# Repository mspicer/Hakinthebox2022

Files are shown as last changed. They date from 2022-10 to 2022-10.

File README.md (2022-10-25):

# Hack-in-the-box 2022 Badge Guide

- PCB.md contains the schematics and pcb layout for each board. This may be helpful for assembly or programming.
- PROGRAM.md contains information on flashing the boards with the current or custom code if desired.

## Assembly

### Step 1
- Solder the attiny85 to the base pcb.

Step 1
### Step 2
- Solder the first two leds on the base pcb.

Step 2
### Step 3
- Solder the last two leds on the base pcb.

Step 3
### Step 4
- Solder the first two leds on the top of the upper pcb.

Step 4
### Step 5
- Solder the next two leds on the top of the upper pcb.

Step 5
### Step 6
- Solder the first two leds on the bottom of the upper pcb.

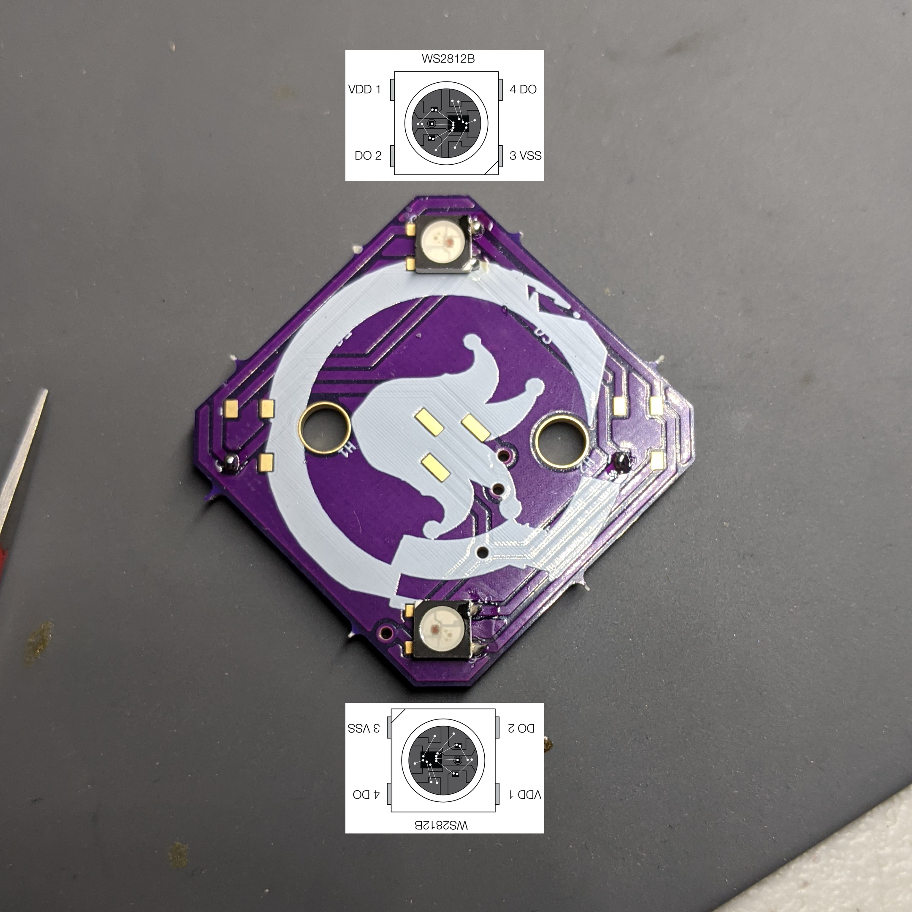
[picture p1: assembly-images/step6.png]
Step 6

### Step 7
- Solder the last two leds on the upper pcb.

Step 7
### Step 8
- Solder the headers on the board by first placing them in the expansion board or similar and then slide the board on to ensure good fit.
Step 8
### Step 9
Step 9
### Step 10
- Remove the stripped ends of the three solid-core wires and attach them to the base pcb.

Step 10
### Step 11
- Solder the solid-core wires to the top. The easiest way is to solder the outer two wires, bend them all 90 degrees, then solder the middle one.

Step 11
### Step 12
- Attach the stand offs to the base pcb with the socket cap screws.

Step 13
### Step 13
Step 14
### Step 14
- With the other screws attach the acrylic and the upper pcb to the standoffs.

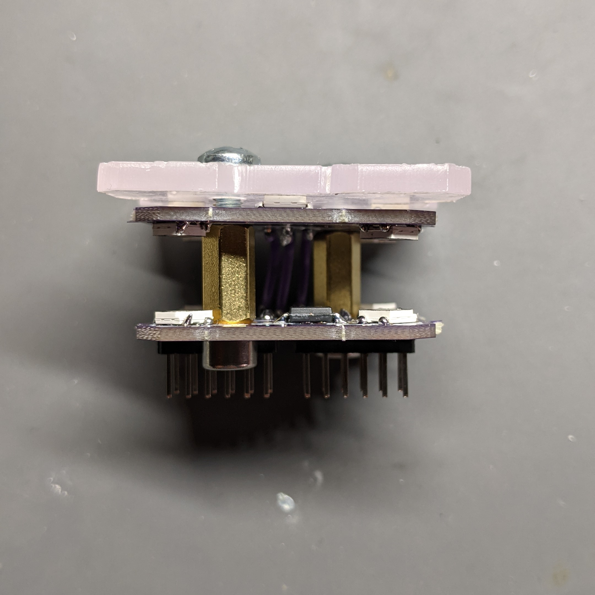
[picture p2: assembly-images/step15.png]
Step 15

### Step 15
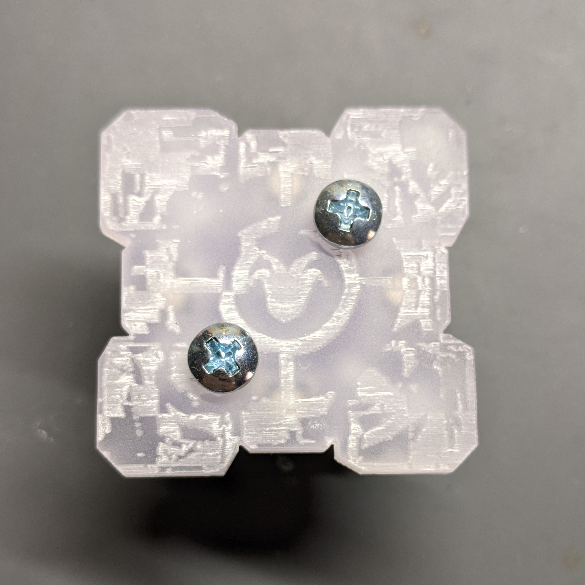
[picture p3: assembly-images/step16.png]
Step 16


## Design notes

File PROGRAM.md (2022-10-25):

# Hack-in-the-box 2022 Programming Guide
- This has been test with Arduino IDE 1.8.18

## Installing Libraries
- Install the ATtiny code by adding this url to the Additional Board Manager URLS: http://drazzy.com/package_drazzy.com_index.json
- More info on this library at https://github.com/SpenceKonde/ATTinyCore

## Programming Connections
- When looking down at the board from above only the lower right six pins are used for programming.

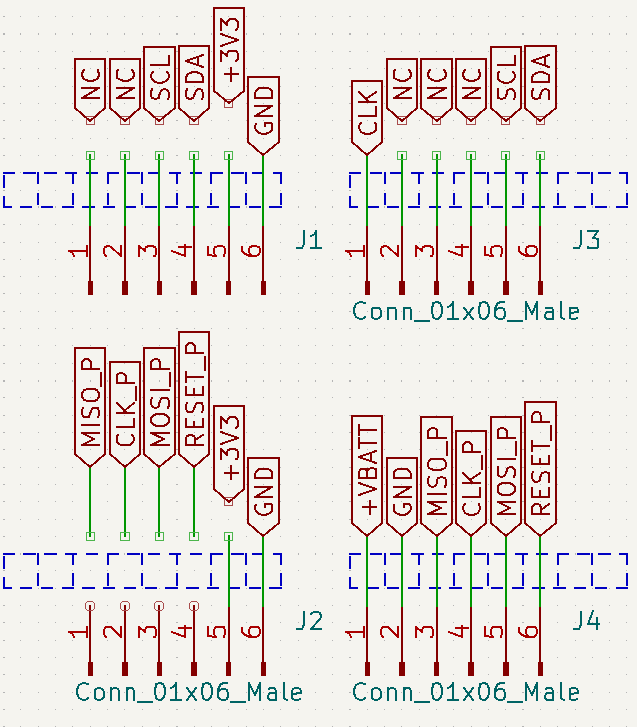
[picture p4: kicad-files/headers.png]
Headers


## Flashing Configuration
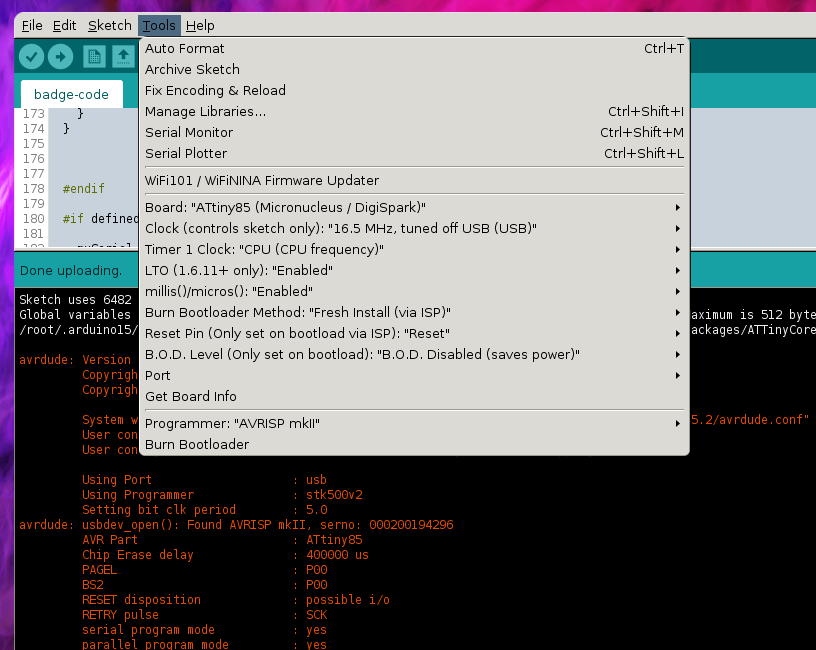
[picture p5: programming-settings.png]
Programming Config


## Flashing
- First select the programmer that you have attached and burn the bootloader
- Then double check the configuration and press Ctrl+Shift+U

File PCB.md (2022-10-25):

# Hack-in-the-box 2022 Badge Schematics and PCB Layout

## Base PCB Schematic
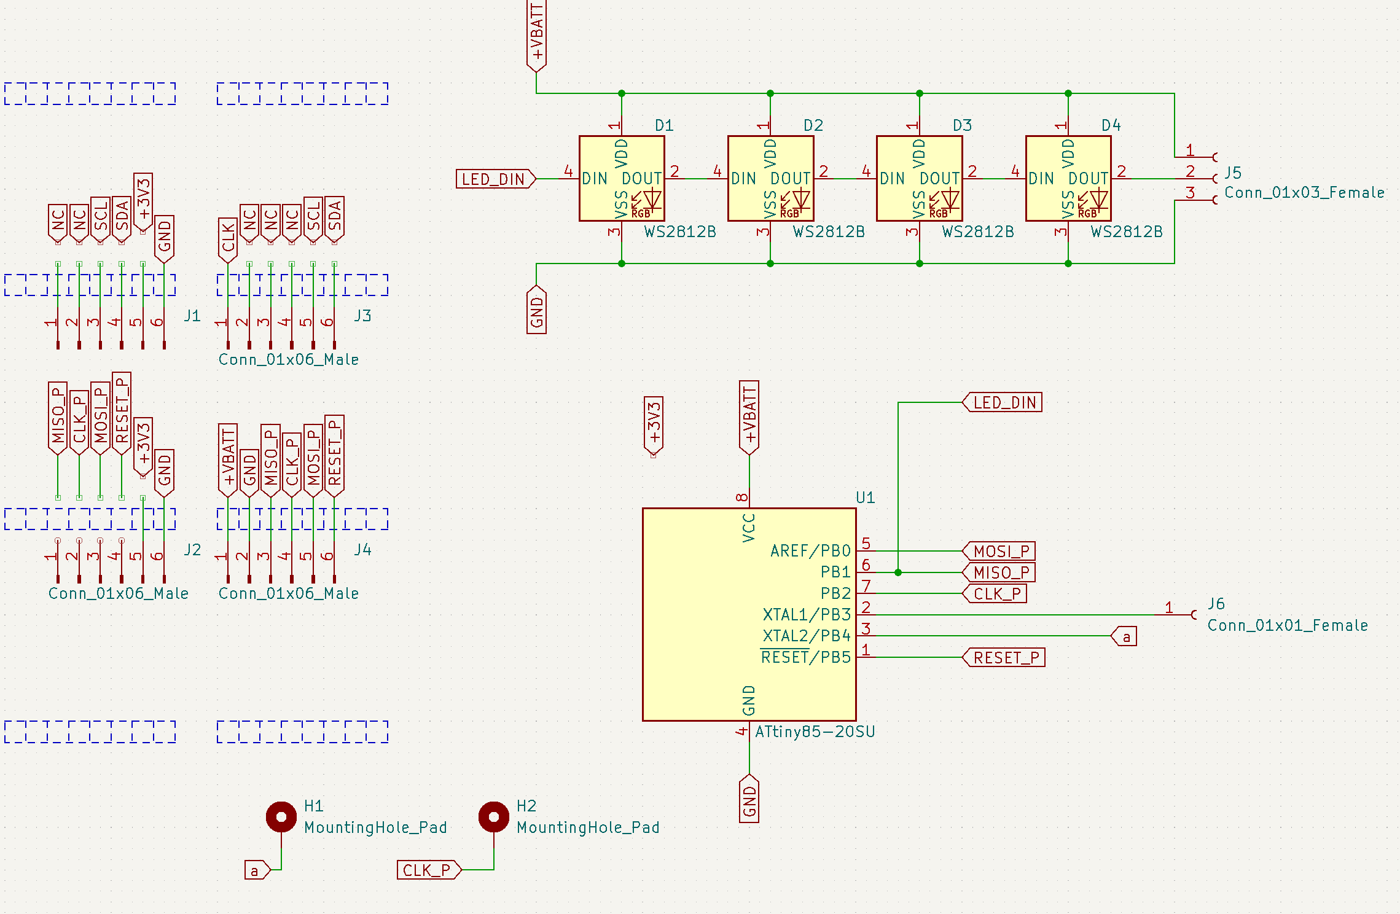
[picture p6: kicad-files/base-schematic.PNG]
Base PCB Schematic


## Upper PCB Schematic
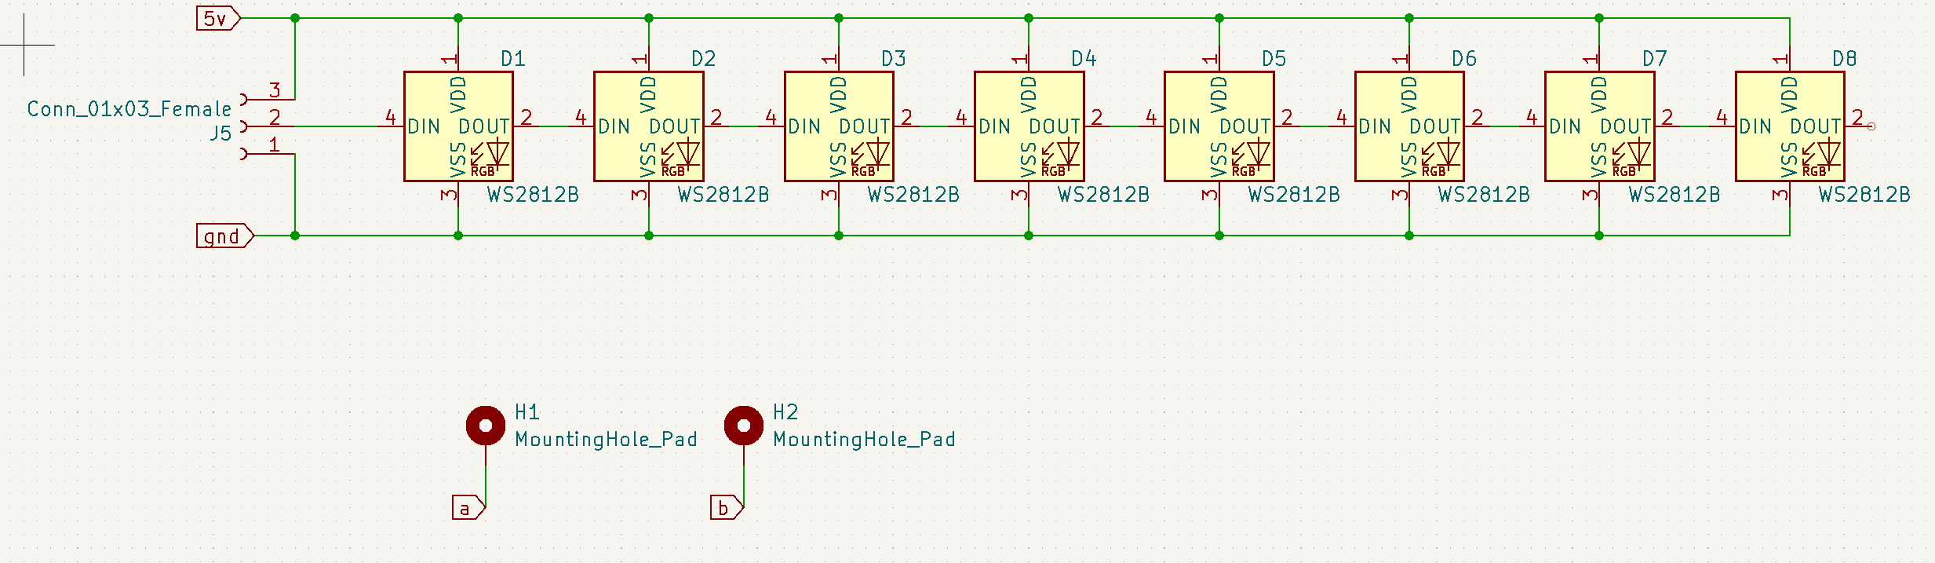
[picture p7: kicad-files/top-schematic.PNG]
Upper PCB Schematic


## Base PCB
### Front/Top
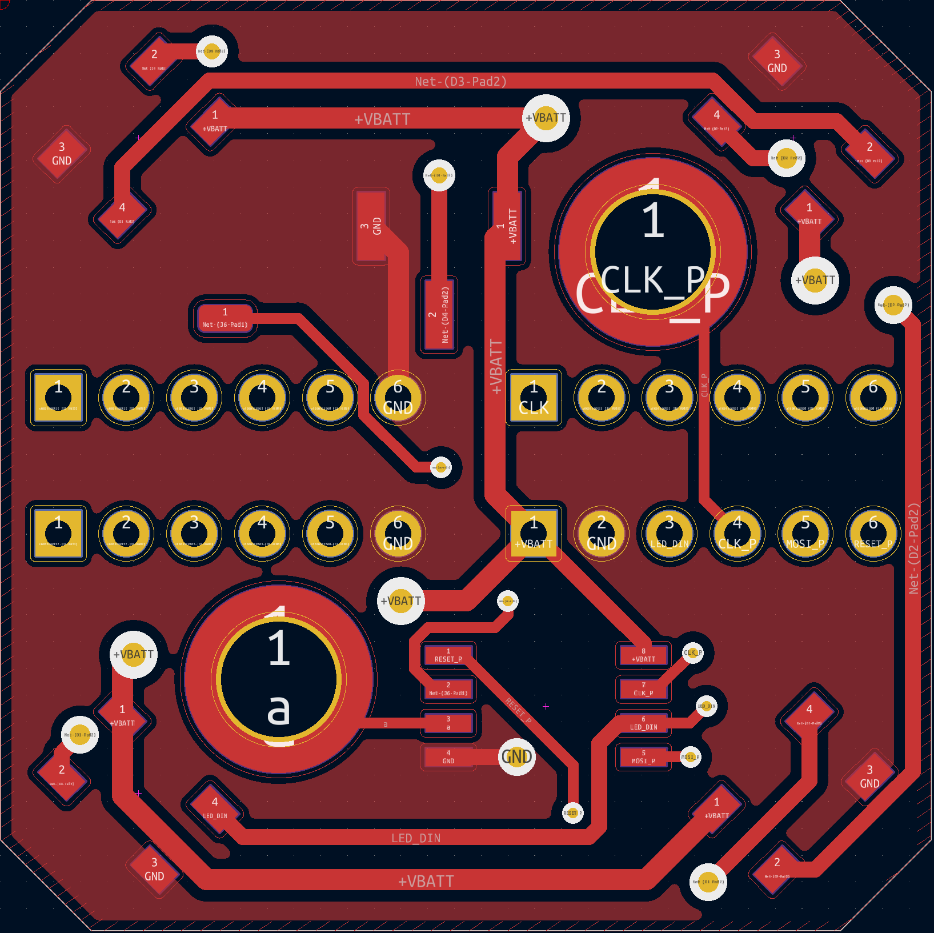
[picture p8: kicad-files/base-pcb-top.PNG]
Base PCB Top


### Back/Bottom
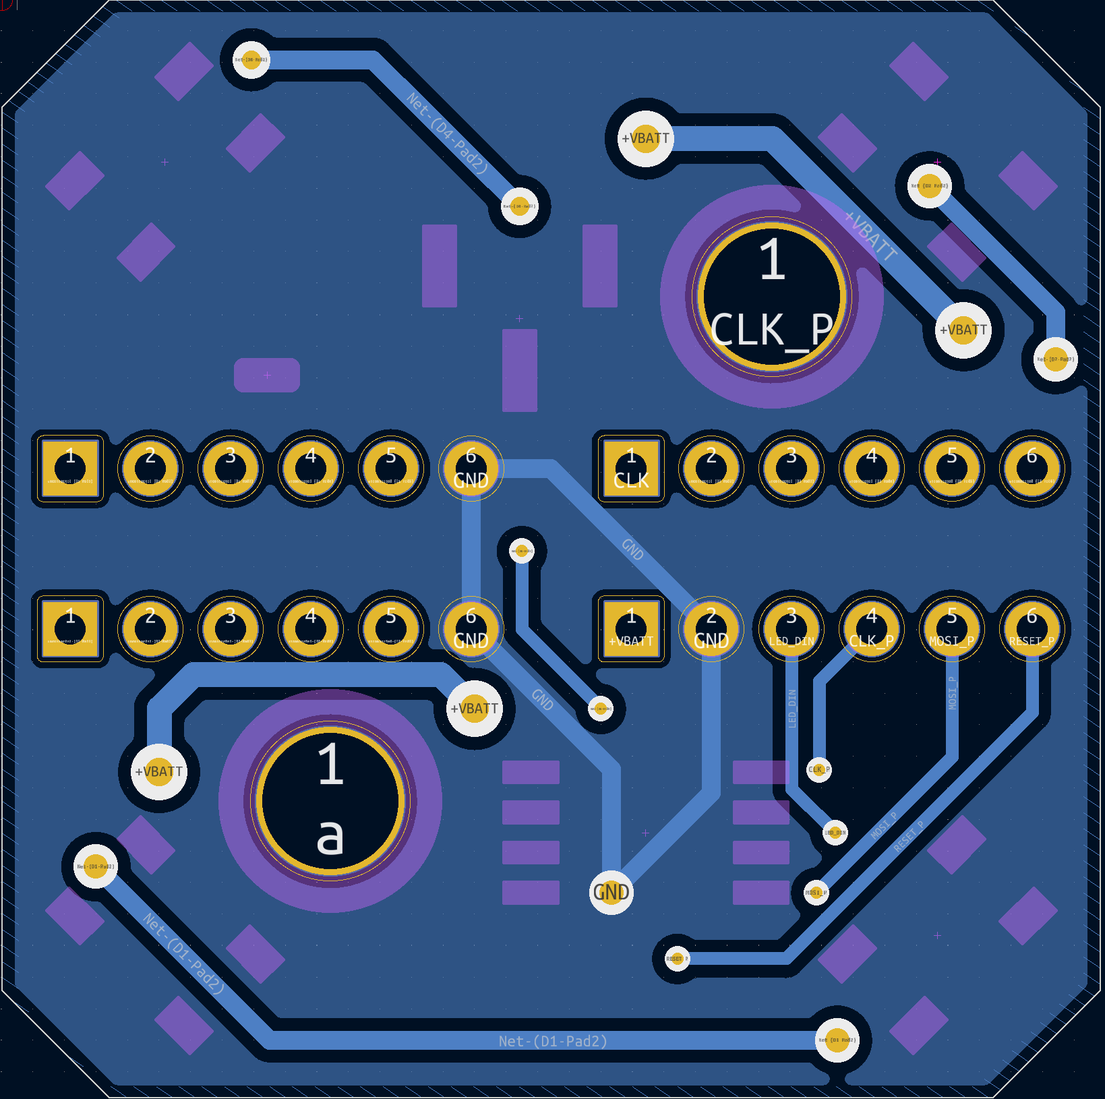
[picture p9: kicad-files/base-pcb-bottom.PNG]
Base PCB Bottom


## Upper PCB
### Front/Top
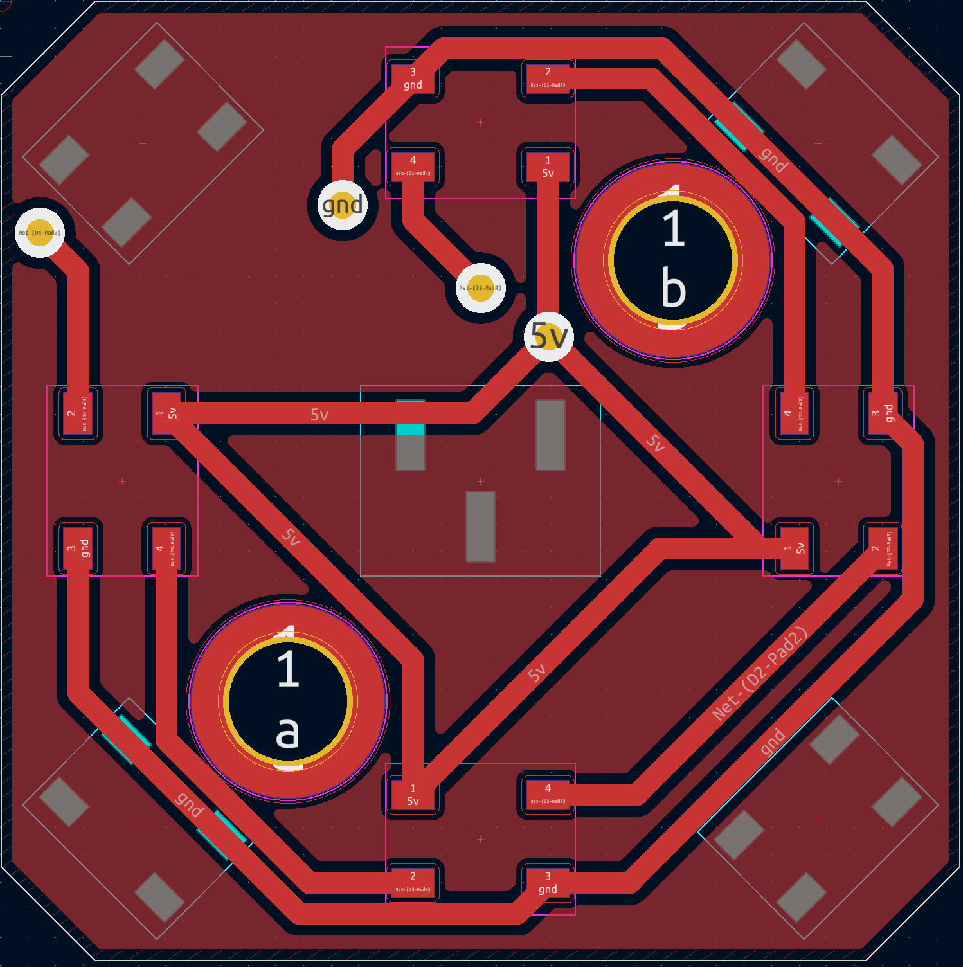
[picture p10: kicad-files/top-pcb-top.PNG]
Upper PCB Top


### Back/Bottom
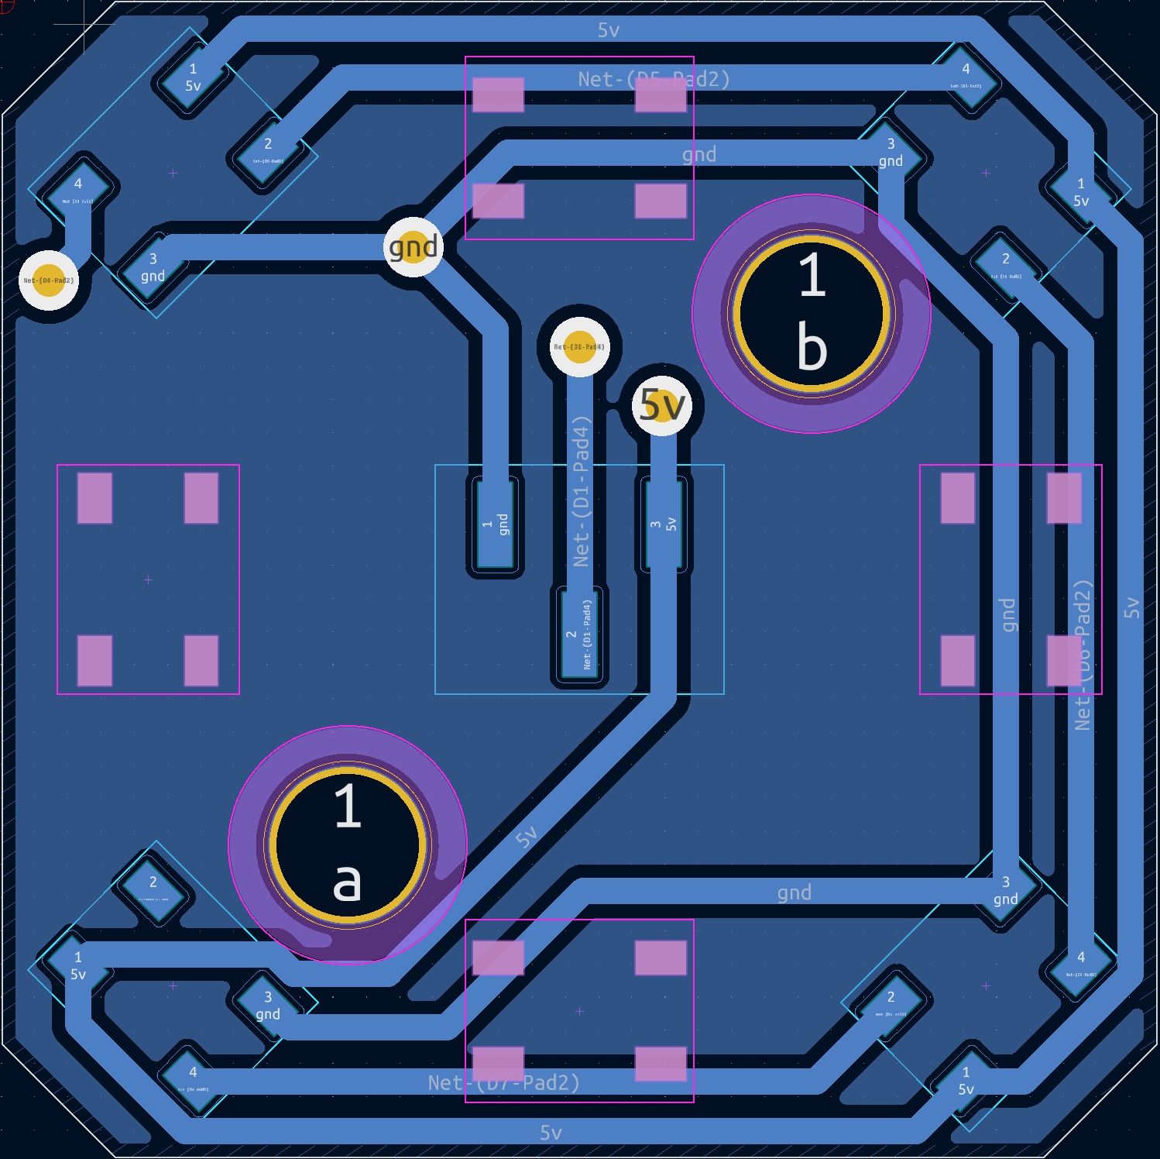
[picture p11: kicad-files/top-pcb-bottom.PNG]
Upper PCB Bottom


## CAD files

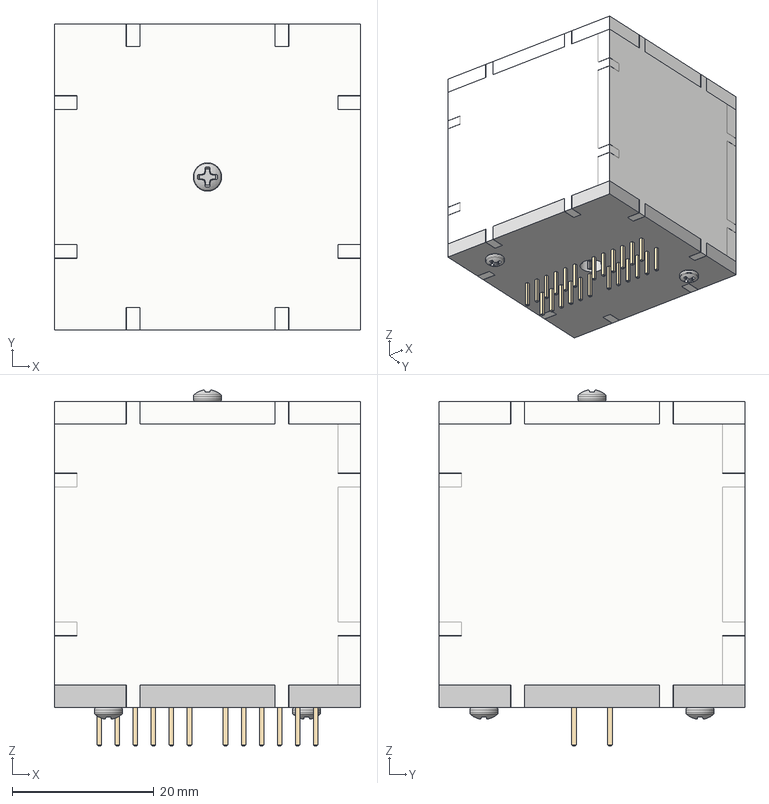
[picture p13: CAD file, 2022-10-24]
kicad-files/base-pcb/assembly v7.step
43.2 x 43.2 x 50.2 mm
Bottom
Side x 4
Top
92000A015_Passivated 18-8 Stainless Steel Pan Head Phillips Screws x 4
standoff

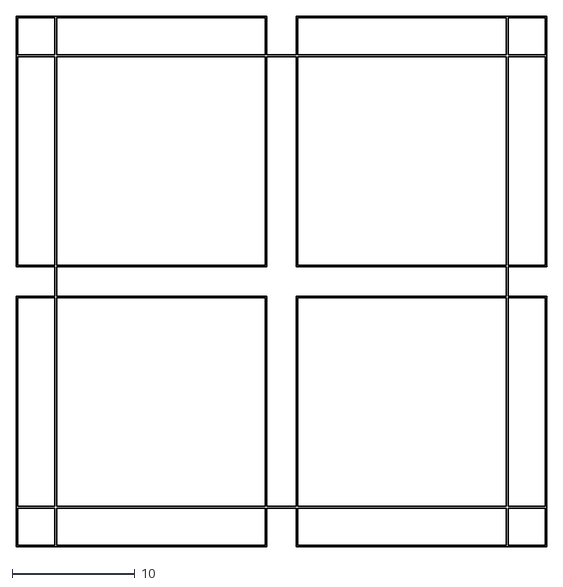
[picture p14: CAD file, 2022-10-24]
kicad-files/base-pcb/companion-Cmts_User.dxf
43.3 x 43.3

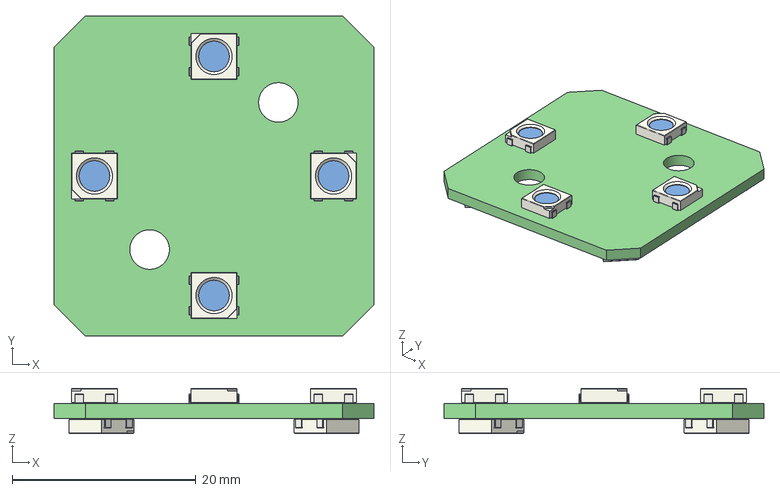
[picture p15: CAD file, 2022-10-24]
kicad-files/top-pcb/companion.step
34.8 x 34.8 x 4.90 mm
companion PCB

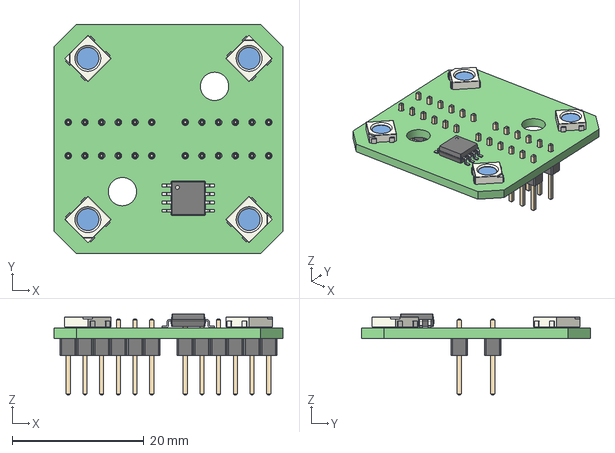
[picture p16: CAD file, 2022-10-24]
kicad-files/base-pcb/companion.step
34.8 x 34.8 x 12.3 mm
companion PCB

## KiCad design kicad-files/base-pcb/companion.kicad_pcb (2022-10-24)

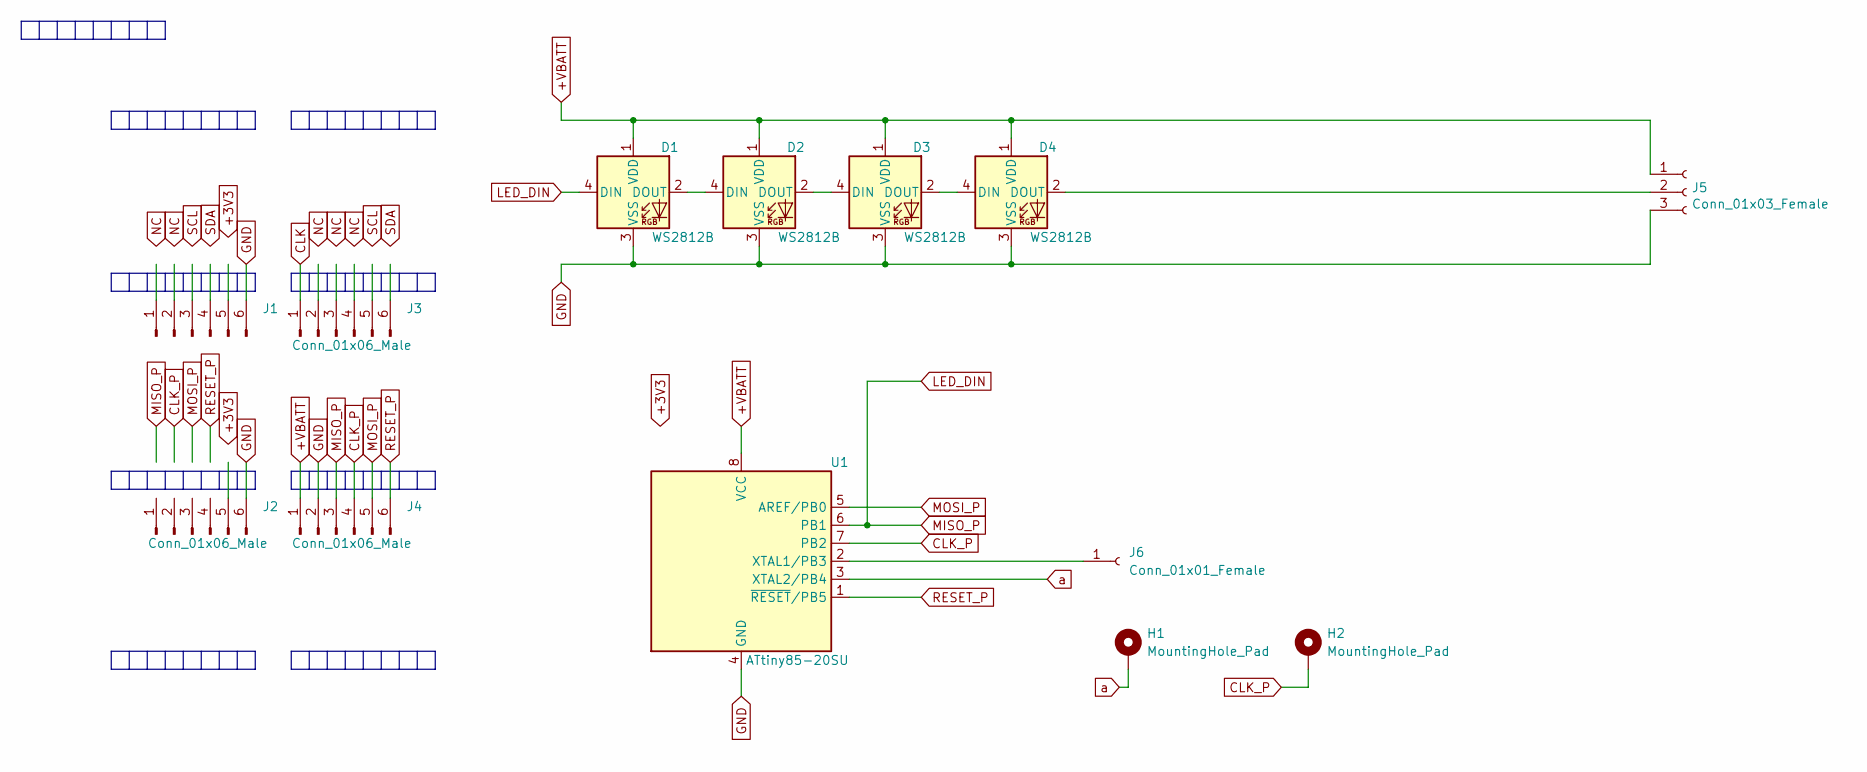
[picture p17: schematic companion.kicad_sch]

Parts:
D1, D2, D3, D4: WS2812B; LED_WS2812B_PLCC4_5.0x5.0mm_P3.2mm
H1, H2: MountingHole_Pad; MountingHole_4.3mm_M4_DIN965_Pad_TopOnly
J1, J2, J3, J4: Conn_01x06_Male; PinHeader_1x06_P2.54mm_Vertical
J5: Conn_01x03_Female; PinHeader_1x03_P2.54mm_Vertical_SMD_Pin1Left
J6: Conn_01x01_Female; SolderWirePad_1x01_SMD_1x2mm
U1: ATtiny85-20SU; SOIJ-8_5.3x5.3mm_P1.27mm

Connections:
+VBATT: D1.1 (VDD), D2.1 (VDD), D3.1 (VDD), D4.1 (VDD), J4.1, J5.1, U1.8 (VCC)
CLK: J3.1
CLK_P: H2.1, J4.4, U1.7 (PB2)
GND: D1.3 (VSS), D2.3 (VSS), D3.3 (VSS), D4.3 (VSS), J1.6, J2.6, J4.2, J5.3, U1.4 (GND)
LED_DIN: D1.4 (DIN), J4.3, U1.6 (PB1)
MOSI_P: J4.5, U1.5 (AREF/PB0)
unnamed: D1.2 (DOUT), D2.4 (DIN)
unnamed: D2.2 (DOUT), D3.4 (DIN)
unnamed: D3.2 (DOUT), D4.4 (DIN)
unnamed: D4.2 (DOUT), J5.2
unnamed: J6.1, U1.2 (XTAL1/PB3)
RESET_P: J4.6, U1.1 (~RESET/PB5)
a: H1.1, U1.3 (XTAL2/PB4)

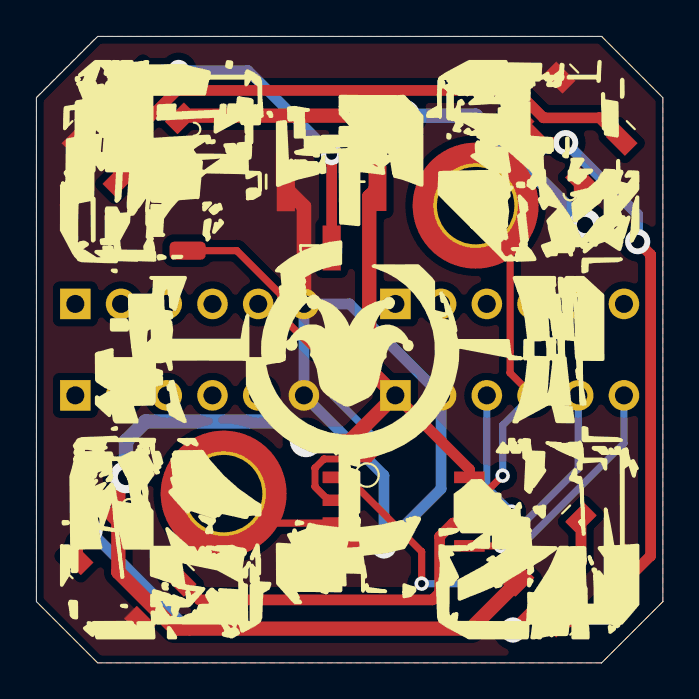
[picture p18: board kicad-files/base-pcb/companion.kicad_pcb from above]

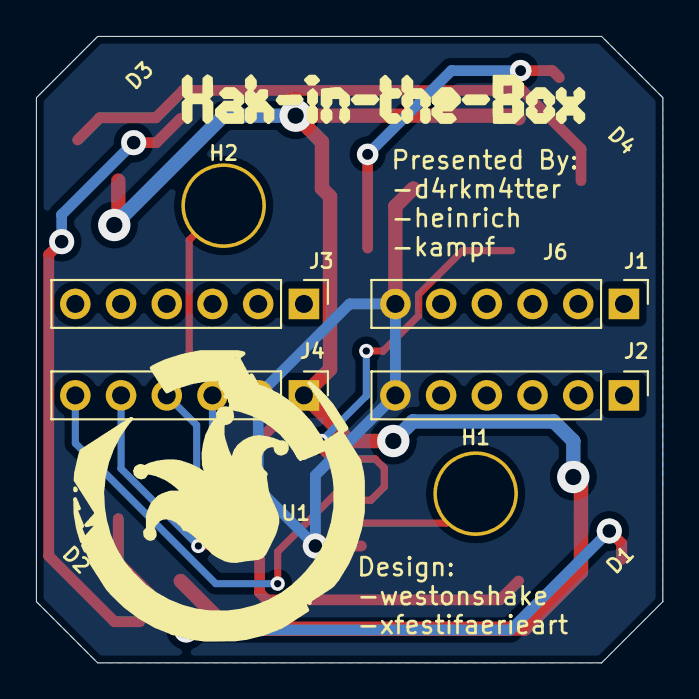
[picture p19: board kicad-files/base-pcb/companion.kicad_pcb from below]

Board: 2 copper layers, 34.8 x 34.8 mm, 13 parts (4 on the bottom side), 12 nets.

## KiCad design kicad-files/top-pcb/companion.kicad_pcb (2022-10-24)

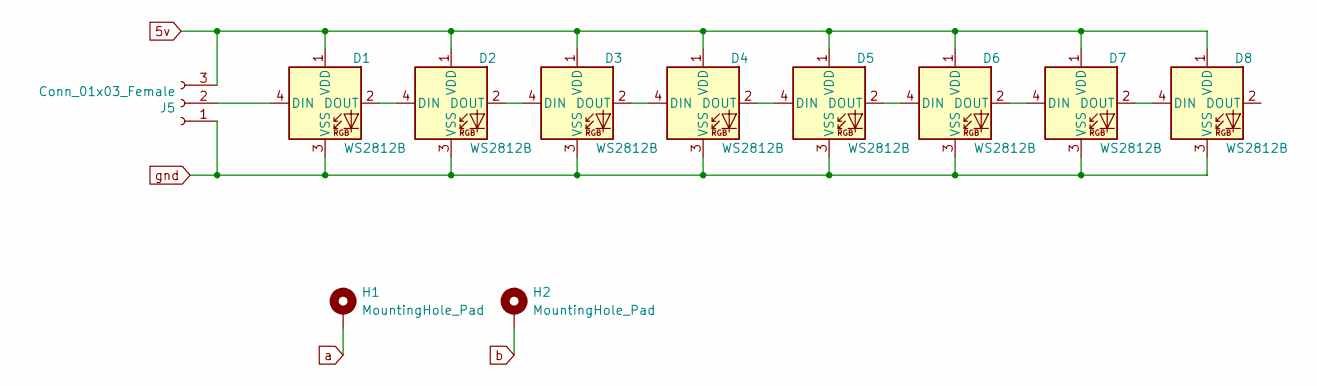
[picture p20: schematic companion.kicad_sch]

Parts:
D1, D2, D3, D4, D5, D6, D7, D8: WS2812B; LED_WS2812B_PLCC4_5.0x5.0mm_P3.2mm
H1, H2: MountingHole_Pad; MountingHole_4.3mm_M4_DIN965_Pad_TopOnly
J5: Conn_01x03_Female; PinHeader_1x03_P2.54mm_Vertical_SMD_Pin1Left

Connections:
5v: D1.1 (VDD), D2.1 (VDD), D3.1 (VDD), D4.1 (VDD), D5.1 (VDD), D6.1 (VDD), D7.1 (VDD), D8.1 (VDD), J5.3
unnamed: D1.2 (DOUT), D2.4 (DIN)
unnamed: D1.4 (DIN), J5.2
unnamed: D2.2 (DOUT), D3.4 (DIN)
unnamed: D3.2 (DOUT), D4.4 (DIN)
unnamed: D4.2 (DOUT), D5.4 (DIN)
unnamed: D5.2 (DOUT), D6.4 (DIN)
unnamed: D6.2 (DOUT), D7.4 (DIN)
unnamed: D7.2 (DOUT), D8.4 (DIN)
a: H1.1
b: H2.1
gnd: D1.3 (VSS), D2.3 (VSS), D3.3 (VSS), D4.3 (VSS), D5.3 (VSS), D6.3 (VSS), D7.3 (VSS), D8.3 (VSS), J5.1

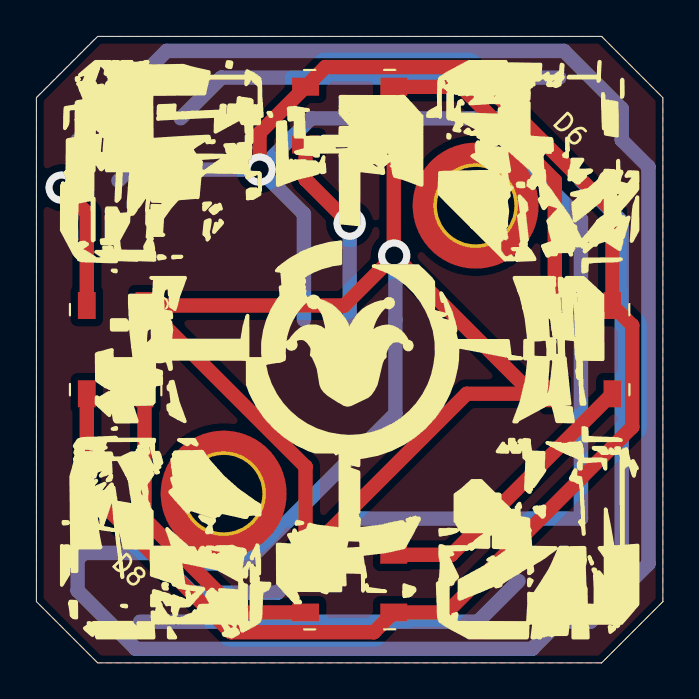
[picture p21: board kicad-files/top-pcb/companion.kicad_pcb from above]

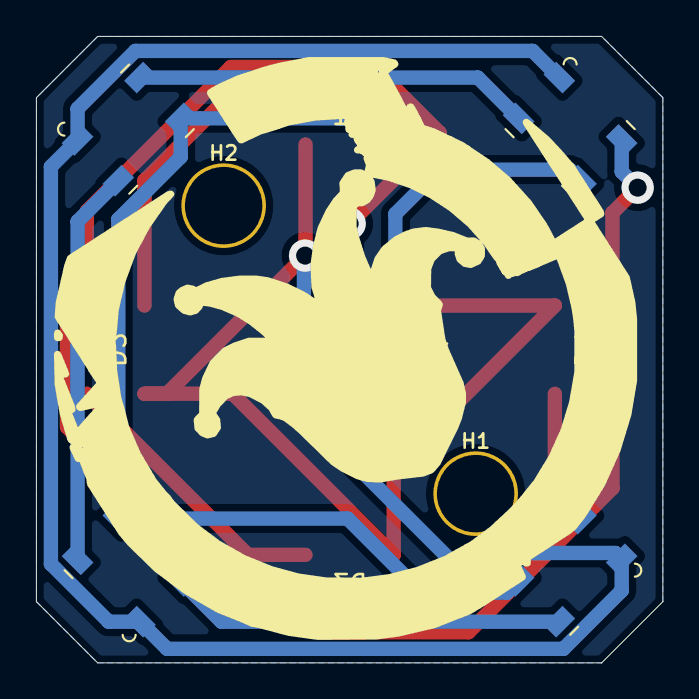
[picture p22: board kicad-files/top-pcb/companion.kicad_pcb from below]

Board: 2 copper layers, 34.8 x 34.8 mm, 11 parts (5 on the bottom side), 10 nets.

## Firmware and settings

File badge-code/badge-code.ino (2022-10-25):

//SAINTCON 2022 Hack in the Box UT Badge Code
//Written by -Weston Shakespear-

// #define DEBUG 1
// #define TEST 1

#define PIN_UART_TX 0
#define PIN_LED_DOUT 1


#define NUM_PIXELS 12

#include <tinyNeoPixel.h>


void HSVtoRGB(int pixel, float H, float S,float V);

#if defined(DEBUG)

  #include <SendOnlySoftwareSerial.h>
  SendOnlySoftwareSerial mySerial(PIN_UART_TX);

#endif


tinyNeoPixel pixels = tinyNeoPixel(NUM_PIXELS, PIN_LED_DOUT, NEO_GRB + NEO_KHZ800);

#define FRAMES 9
const int frames[FRAMES][12] = {
  {1, 0, 0, 1, 0, 0, 0, 1, 1, 0, 0, 1}, //0left
  {0, 0, 0, 0, 1, 0, 1, 0, 0, 0, 0, 0}, //1mid left
  {0, 1, 1, 0, 0, 1, 0, 0, 0, 1, 1, 0}, //2right
  {1, 1, 0, 0, 0, 0, 1, 0, 0, 0, 1, 1}, //3front
  {0, 0, 0, 0, 0, 1, 0, 1, 0, 0, 0, 0}, //4mid front
  {0, 0, 1, 1, 1, 0, 0, 0, 1, 1, 0, 0}, //5back
  {1, 1, 1, 1, 0, 0, 0, 0, 0, 0, 0, 0}, //6base
  {0, 0, 0, 0, 1, 1, 1, 1, 0, 0, 0, 0}, //7mid
  {0, 0, 0, 0, 0, 0, 0, 0, 1, 1, 1, 1}, //8top
};

#define ANIMS 4
const int anims[ANIMS][4] = {
                            {0, 5, 2, 3},
                            {0, 2, 0, 2},
                            {3, 5, 3, 5},
                            {6, 7, 8, 7}
                          };

void setup() {
  pixels.begin();
  pixels.setBrightness(100);

  #if defined(DEBUG)

    mySerial.begin(9600);

  #endif

}

void loop() {

  #if defined(TEST)


  int H = 180 + (180 * sin(millis()/100));
  int S = 50 + (50 * sin(millis()/150));
  int V = 50 + (50 * sin(millis()/20));
  for (int i = 0; i < NUM_PIXELS; i++) {
    HSVtoRGB(i, H, S, V);
    // pixels.setPixelColor(i, pixels.Color(40, 0, 0));

    if (i != 0) {
      pixels.setPixelColor(i-4, pixels.Color(0, 0, 0));
    } else {
      pixels.setPixelColor(NUM_PIXELS - 1, pixels.Color(0, 0, 0));
      pixels.setPixelColor(NUM_PIXELS - 2, pixels.Color(0, 0, 0));
      pixels.setPixelColor(NUM_PIXELS - 3, pixels.Color(0, 0, 0));
      pixels.setPixelColor(NUM_PIXELS - 4, pixels.Color(0, 0, 0));
    }

    pixels.show();
    delay(100);
  }
  for (int i = 0; i < NUM_PIXELS; i++) {
    pixels.setPixelColor(i, pixels.Color(0, 0, 0));
    pixels.show();
    delay(20);
  }



  #else

  int MIN_RANDOM = -1 * random(0, 4);
  int CHANCE_ANIM = random(0, 6);

  int CHANCE_WIPE_NO = -1 * random(0, 2);
  int CHANCE_WIPE_YES = random(0, 2);

  int UPDATE_H_Y = -1 * random(0, 4);
  int UPDATE_H_N = random(0, 4);

  int UPDATE_S_Y = -1 * random(0, 4);
  int UPDATE_S_N = random(0, 4);

  int UPDATE_V_Y = -1 * random(0, 4);
  int UPDATE_V_N = random(0, 4);

  int UPDATE_DELAY_CHANCE = random(0, 8);

  int anim = -1;
  int frame = 0;
  int wipe = 0;
  int custom[4] = {1, 5, 3, 2};

  int H = 180 + (180 * sin(millis()/100));
  int S = 75 + (25 * sin(millis()/150));
  int V = 50 + (50 * sin(millis()/20));

  byte delayTime = 100;

  while (true) {
    if (random(UPDATE_H_Y, UPDATE_H_N) < 0) {
      H = 180 + (180 * sin(millis()/100));
    }

    if (random(UPDATE_S_Y, UPDATE_S_N) < 0) {
      S = 75 + (25 * sin(millis()/150));
    }

    if (random(UPDATE_V_Y, UPDATE_V_N) < 0) {
      V = 50 + (50 * sin(millis()/20));
    }

    if (random(0, CHANCE_ANIM) == 1) {
      anim = random(MIN_RANDOM, ANIMS);
    }

    wipe = random(CHANCE_WIPE_NO, CHANCE_WIPE_YES);


    if (anim < 0) {
      for (int i = 0; i < 4; i++) {
        custom[i] = random(0, FRAMES);
      }
    }

    for (int section = 0; section < 4; section++) {
      if (anim < 0) {
        frame = custom[section];
      } else {
        frame = anims[anim][section];
      }


      for (int led = 0; led < 12; led++) {
        if (frames[frame][led] == 1) {
          HSVtoRGB(led, H, S, V);
        } else {
          if (wipe > 0) {
            pixels.setPixelColor(led, pixels.Color(0, 0, 0));
          }

        }
      }
      pixels.show();
      if (random(0, UPDATE_DELAY_CHANCE) == 0) {
        delayTime = 5 * random(10, 100);
      }
      delay(delayTime);

    }
  }



  #endif

  #if defined(DEBUG)

    mySerial.println("hello from debug stuff");

  #endif

}

void HSVtoRGB(int pixel, float H, float S,float V) {
    float s = S/100;
    float v = V/100;
    float C = s*v;
    float X = C*(1-abs(fmod(H/60.0, 2)-1));
    float m = v-C;
    float r,g,b;
    if(H >= 0 && H < 60){
        r = C,g = X,b = 0;
    }
    else if(H >= 60 && H < 120){
        r = X,g = C,b = 0;
    }
    else if(H >= 120 && H < 180){
        r = 0,g = C,b = X;
    }
    else if(H >= 180 && H < 240){
        r = 0,g = X,b = C;
    }
    else if(H >= 240 && H < 300){
        r = X,g = 0,b = C;
    }
    else{
        r = C,g = 0,b = X;
    }
    int R = (r+m)*255;
    int G = (g+m)*255;
    int B = (b+m)*255;
    pixels.setPixelColor(pixel, pixels.Color(R, G, B));

}

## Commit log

2022-10-24 kicad files
    [assembly v7.step, companion - top.kicad_pcb, companion-Cmts_User.dxf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]
2022-10-25 added assembly images
